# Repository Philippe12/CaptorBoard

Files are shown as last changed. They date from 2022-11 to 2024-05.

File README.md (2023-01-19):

# CaptorBoard
## Decription
Lite automated board with tow relai, one one wire for DHT11, one i2c busse, gpio and UART.
This board is build around a esp32 and designed for Esphome OS.

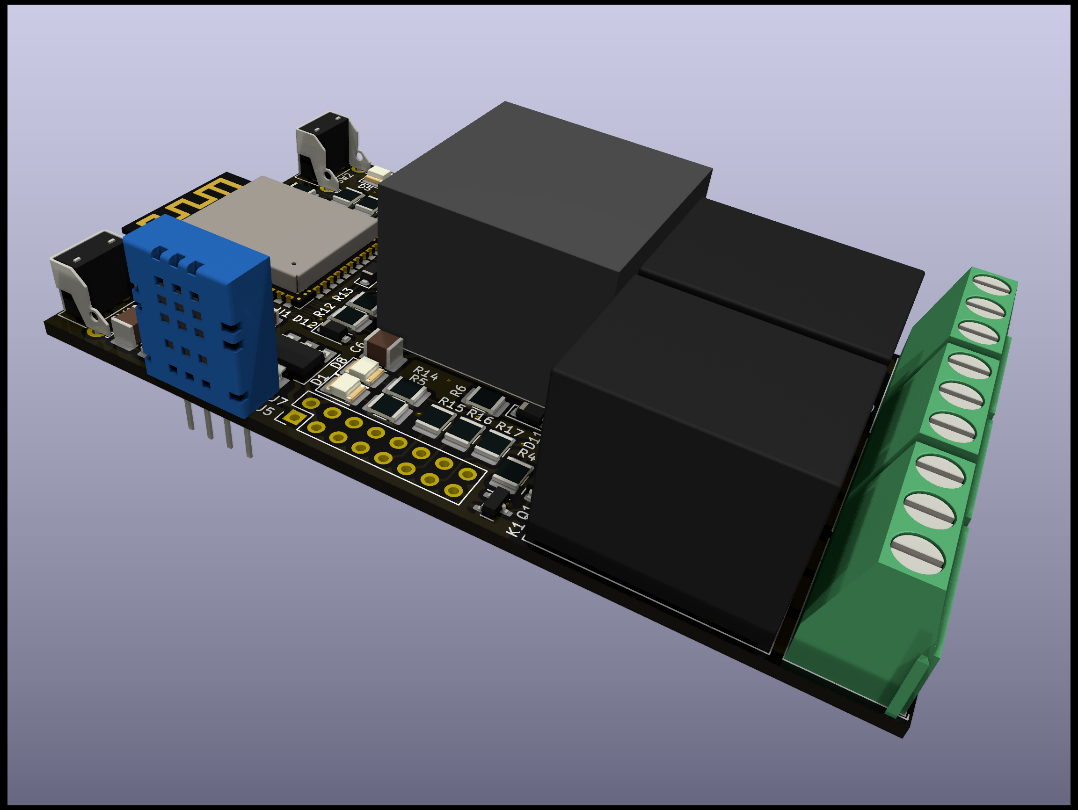
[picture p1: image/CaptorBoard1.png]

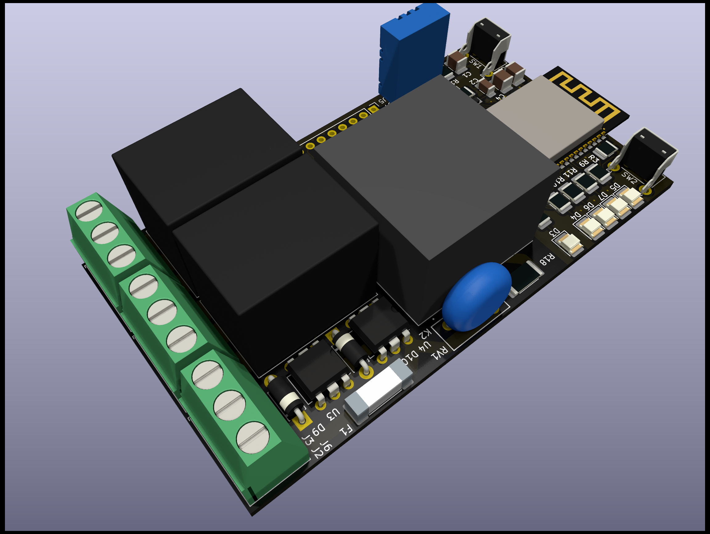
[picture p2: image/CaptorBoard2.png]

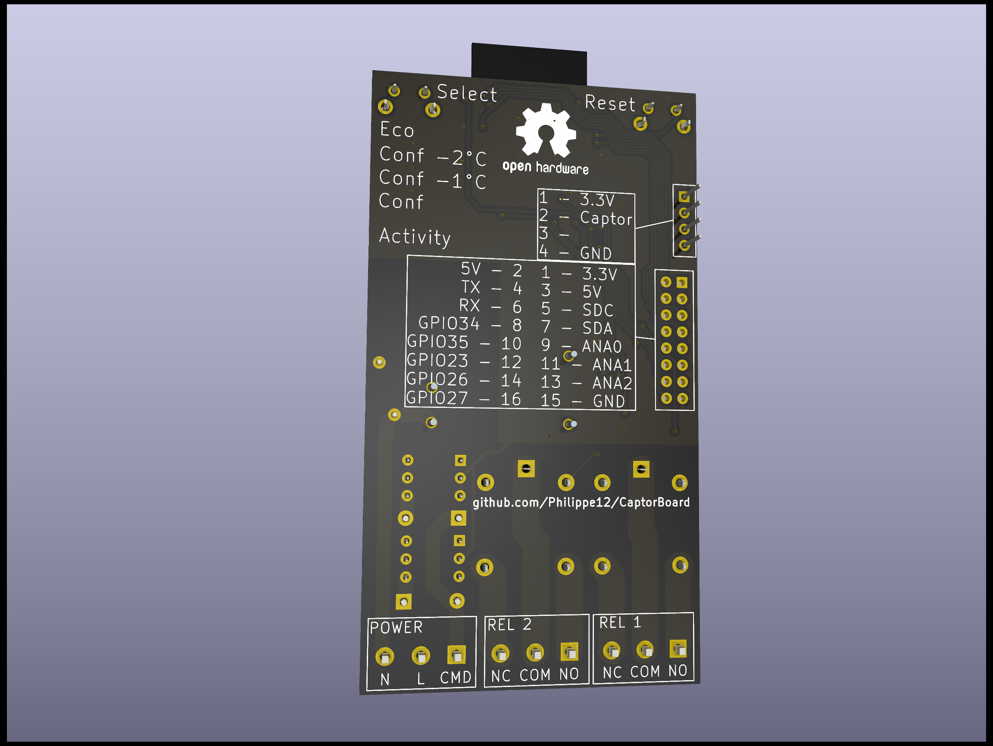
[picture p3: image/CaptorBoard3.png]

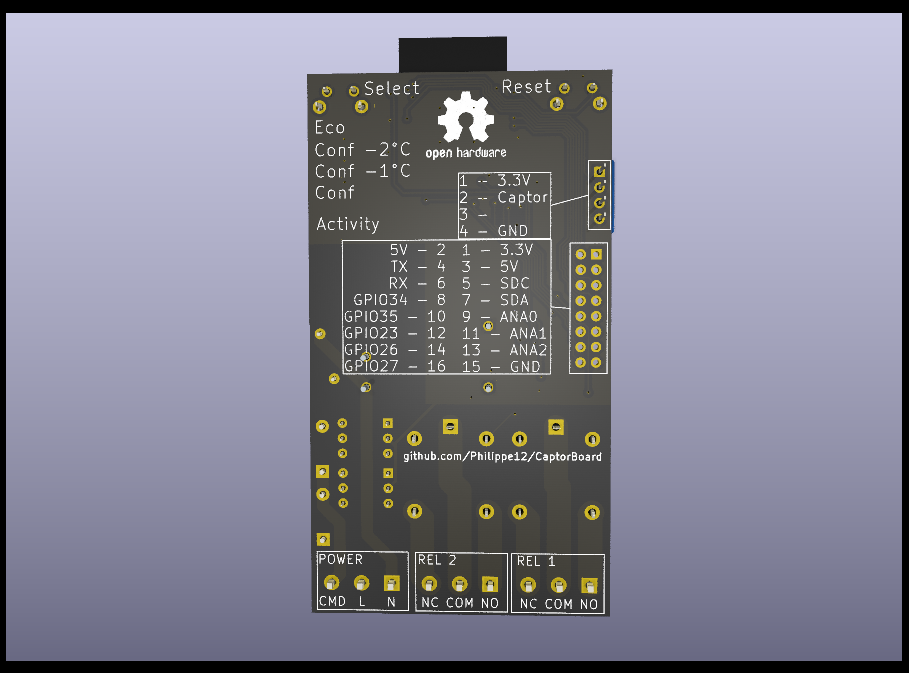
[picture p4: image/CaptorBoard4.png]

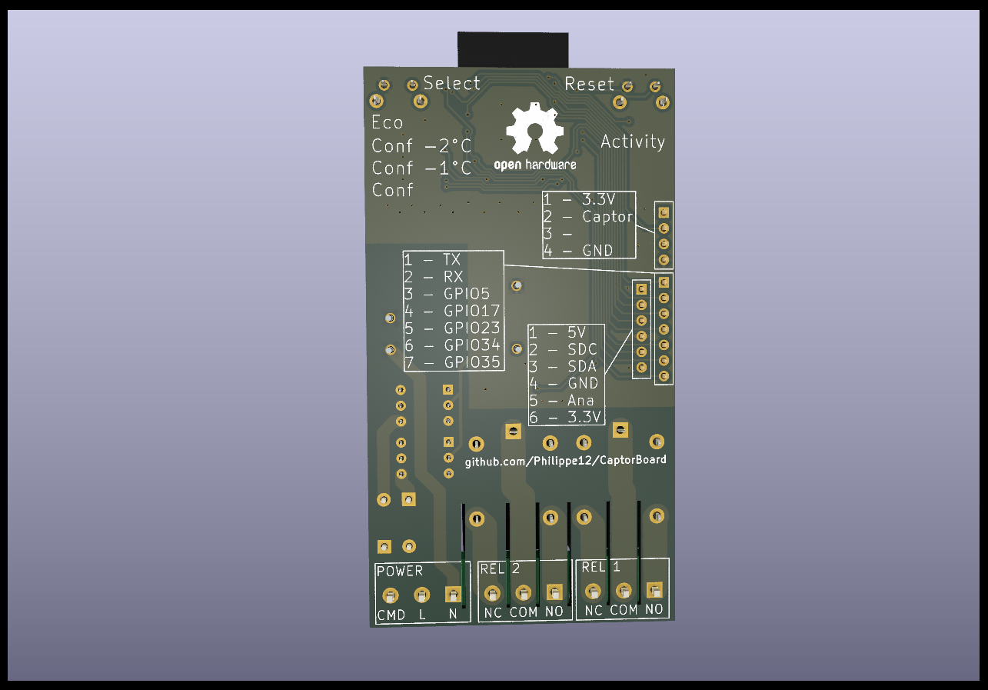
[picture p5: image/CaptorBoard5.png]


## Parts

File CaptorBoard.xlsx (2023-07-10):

Prj: | CaptorBoart |  |  |  | Board Qty: | 1
Co.: |  |  |  |  | Unit Cost: | €26.97
Prj date: | 28/06/2023 17:16:08 |  |  |  | Total Cost: | €26.97 |  |  |  |  | €26.97 | 24 of 24 parts found
$ date: | 2023-06-28 17:16:14
Global Part Info |  |  |  |  |  |  | Digi-Key
Refs | Value | Footprint | Manf# | Qty | Unit$ | Ext$ | Avail | Purch | Unit$ | MOQ | Ext$ | Cat#
C1,C6 | 1µ | C_1210_3225Metric_Pad1.33x2.70mm_HandSolder | CL32B105KBHNNNE (https://www.mouser.fr/datasheet/2/585/MLCC-1837944.pdf) | 2 | €0.210 | €0.42 | 404544 |  | €0.210 | 1 | €0.42 | 1276-1811-1-ND (https://www.digikey.com/en/products/detail/samsung-electro-mechanics/CL32B105KBHNNNE/3887469)
C2,C3 | 12p | C_1206_3216Metric_Pad1.33x1.80mm_HandSolder | C1206C120J5GAC7800 (https://www.mouser.fr/datasheet/2/212/KEM_C1007_X8R_ULTRA_150C_SMD-1102703.pdf) | 2 | €0.201 | €0.40 | 17043 |  | €0.201 | 1 | €0.40 | 399-C1206C120J5GAC7800CT-ND (https://www.digikey.com/en/products/detail/kemet/C1206C120J5GAC7800/411192)
C4 | 22µ | C_1210_3225Metric_Pad1.33x2.70mm_HandSolder | CL32A226MOJNNNE (https://www.mouser.fr/datasheet/2/585/MLCC-1837944.pdf) | 1 | €0.320 | €0.32 | 384377 |  | €0.320 | 1 | €0.32 | 1276-1851-1-ND (https://www.digikey.com/en/products/detail/samsung-electro-mechanics/CL32A226MOJNNNE/3887509)
C5 | 0.1µ | C_1210_3225Metric_Pad1.33x2.70mm_HandSolder | 12101C104K4T2A (https://www.mouser.fr/datasheet/2/40/AutoMLCC-777028.pdf) | 1 | €0.238 | €0.24 | 11066 |  | €0.238 | 1 | €0.24 | 478-KAM32QR72A104KTCT-ND (https://www.digikey.com/en/products/detail/kyocera-avx/KAM32QR72A104KT/6149343)
D1,D3-D8 | LTST-C930KGKT | LED_1210_3225Metric_Pad1.42x2.65mm_HandSolder | LTST-C930KGKT (https://www.mouser.fr/datasheet/2/239/LTST-C930KGKT-1144029.pdf) | 7 | €0.329 | €2.30 | 177523 |  | €0.329 | 1 | €2.30 | 160-1462-1-ND (https://www.digikey.com/en/products/detail/liteon/LTST-C930KGKT/386865)
D2,D11 | 1N4148W | D_SOD-123 | 1N4148W-E3-08 (https://www.vishay.com/docs/85748/1n4148w.pdf) | 2 | €0.210 | €0.42 | 52054 |  | €0.210 | 1 | €0.42 | 1N4148W-E3-08CT-ND (https://www.digikey.com/en/products/detail/vishay-general-semiconductor-diodes-division/1N4148W-E3-08/3104162)
D9,D10 | 1N4004 | D_DO-41_SOD81_P7.62mm_Horizontal | 1N4004RLG (http://www.vishay.com/docs/88503/1n4001.pdf) | 2 | €0.247 | €0.49 | 57339 |  | €0.247 | 1 | €0.49 | 1N4004RLGOSCT-ND (https://www.digikey.com/en/products/detail/onsemi/1N4004RLG/822782)
D12-D14 | BZT52-C3V3 | D_SOD-123F | BZT52-C3V3_R1_00001 (https://diotec.com/tl_files/diotec/files/pdf/datasheets/bzt52b2v4.pdf) | 3 | €0.137 | €0.41 | 12932 |  | €0.137 | 1 | €0.41 | 3757-BZT52-C3V3_R1_00001CT-ND (https://www.digikey.com/en/products/detail/panjit-international-inc/BZT52-C3V3-R1-00001/14660565)
F1 | Fuse_Small-device | Fuseholder_Littelfuse_Nano2_157x | 3405.0166.11 (https://www.mouser.fr/datasheet/2/240/Littelfuse_Fuse_443_Datasheet_pdf-1102277.pdf) | 1 | €0.567 | €0.57 | 235 |  | €0.567 | 1 | €0.57 | 486-4956-ND (https://www.digikey.com/en/products/detail/schurter-inc/3405-0166-11/9094749)
J2,J3,J6 | Screw_Terminal_01x03 | TerminalBlock_Phoenix_MKDS-1,5-3-5.08_1x03_P5.08mm_Horizontal | TB007-508-03BE (https://www.mouser.fr/datasheet/2/670/tb007_508-2306759.pdf) | 3 | €0.887 | €2.66 | 3935 |  | €0.887 | 1 | €2.66 | 102-6204-ND (https://www.digikey.com/en/products/detail/cui-devices/TB007-508-03BE/10064128)
K1,K2 | G5LE-1-DC5 | Relay_SPDT_Omron-G5LE-1 | G5LE-1-DC5 (http://www.omron.com/ecb/products/pdf/en-g5le.pdf) | 2 | €1.518 | €3.04 | 6959 |  | €1.518 | 1 | €3.04 | Z1014-ND (https://www.digikey.com/en/products/detail/omron-electronics-inc-emc-div/G5LE-1-DC5/280368)
PS1 | LD03-23B05R2 | PSK5D5 | LD03-23B05R2 (https://www.mouser.fr/datasheet/2/670/psk_5d-2474718.pdf) | 1 | €4.873 | €4.87 | 10414 |  | €4.873 | 1 | €4.87 | 2725-LD03-23B05R2-ND (https://www.digikey.com/en/products/detail/mornsun-america-llc/LD03-23B05R2/13531047)
Q1,Q2 | 2N7002E | SOT-23 | T2N7002BK,LM (http://www.diodes.com/assets/Datasheets/ds30376.pdf) | 2 | €0.155 | €0.31 | 266755 |  | €0.155 | 1 | €0.31 | T2N7002BKLMCT-ND (https://www.digikey.com/en/products/detail/toshiba-semiconductor-and-storage/T2N7002BK-LM/5409245)
R1,R5,R7-R11,R14 | 1k | R_1210_3225Metric_Pad1.30x2.65mm_HandSolder | RMCF1210JT1K00 (https://www.mouser.fr/datasheet/2/210/Kamaya_RMC_series_8_2022-3032447.pdf) | 8 | €0.110 | €0.88 | 207265 |  | €0.110 | 1 | €0.88 | RMCF1210JT1K00CT-ND (https://www.digikey.com/en/products/detail/stackpole-electronics-inc/RMCF1210JT1K00/1757278)
R2 | 5M | R_1210_3225Metric_Pad1.30x2.65mm_HandSolder | CRMA1210AF4M99FKEF (https://www.mouser.fr/datasheet/2/427/crma-1765222.pdf) | 1 | €0.631 | €0.63 | 7720 |  | €0.631 | 1 | €0.63 | 3579-CRMA1210AF4M99FKEFCT-ND (https://www.digikey.com/en/products/detail/vishay-techno/CRMA1210AF4M99FKEF/13998628)
R3,R4,R6,R15-R17 | 10k | R_1210_3225Metric_Pad1.30x2.65mm_HandSolder | RMCF1210FT10K0 (https://www.mouser.fr/datasheet/2/219/RK73B-1825463.pdf) | 6 | €0.128 | €0.77 | 17980 |  | €0.128 | 1 | €0.77 | RMCF1210FT10K0CT-ND (https://www.digikey.com/en/products/detail/stackpole-electronics-inc/RMCF1210FT10K0/1758528)
R12,R13 | 560R | R_1210_3225Metric_Pad1.30x2.65mm_HandSolder | RK73B2ETTD561J (https://www.mouser.fr/datasheet/2/219/RK73B-1825463.pdf) | 2 | €0.128 | €0.26 | 15215 |  | €0.128 | 1 | €0.26 | 2019-RK73B2ETTD561JCT-ND (https://www.digikey.com/en/products/detail/koa-speer-electronics-inc/RK73B2ETTD561J/10314965)
R18 | 12 | R_2512_6332Metric_Pad1.40x3.35mm_HandSolder | 352212RJT | 1 | €0.622 | €0.62 | 113856 |  | €0.622 | 1 | €0.62 | A121136CT-ND (https://www.digikey.com/en/products/detail/te-connectivity-passive-product/352212RJT/5244987)
RV1 | B72210S0351K101 | RV_Disc_D12mm_W5.1mm_P7.5mm | B72210S0351K101 | 1 | €0.466 | €0.47 | 6900 |  | €0.466 | 1 | €0.47 | 495-6461-ND (https://www.digikey.com/en/products/detail/epcos-tdk-electronics/B72210S0351K101/3500863)
SW1,SW2 | SW_PUSH | SW_Tactile_SKHH_Angled | TL1105VF100Q (https://www.mouser.fr/datasheet/2/15/SKHH-1370651.pdf) | 2 | €0.338 | €0.68 | 66274 |  | €0.338 | 1 | €0.68 | EG2507-ND (https://www.digikey.com/en/products/detail/e-switch/TL1105VF100Q/378973)
U1 | ESP32-WROOM-32E-H4 | ESP32-WROOM-32E | ESP32-WROOM-32E-H4 (https://www.espressif.com/sites/default/files/documentation/esp32-wroom-32e_esp32-wroom-32ue_datasheet_en.pdf) | 1 | €2.880 | €2.88 | 9799 |  | €2.880 | 1 | €2.88 | 1965-ESP32-WROOM-32E-H4CT-ND (https://www.digikey.com/en/products/detail/espressif-systems/ESP32-WROOM-32E-H4/12696413)
U2 | TC1264-3.3VDBTR | SOT-223-3_TabPin2 | TC1264-3.3VDBTR (http://ww1.microchip.com/downloads/en/DeviceDoc/21373C.pdf) | 1 | €0.832 | €0.83 | 545 |  | €0.832 | 1 | €0.83 | TC1264-3.3VDBCT-ND (https://www.digikey.com/en/products/detail/microchip-technology/TC1264-3-3VDBTR/443075)
U3,U4 | MOC3041M-opto | DIP-6_W7.62mm | MOC3041M (https://www.mouser.fr/datasheet/2/308/1/MOC3043M_D-1811826.pdf) | 2 | €0.978 | €1.96 | 4749 |  | €0.978 | 1 | €1.96 | MOC3041M-ND (https://www.digikey.com/en/products/detail/onsemi/MOC3041M/281230)
Y1 | CM8V-T1A-32.768kHz-12.5pF-20PPM-TA-QC | Crystal_SMD_MicroCrystal_CC8V-T1A-2Pin_2.0x1.2mm_HandSoldering | CM8V-T1A-32.768kHz-12.5pF-20PPM-TA-QC (https://www.mouser.fr/datasheet/2/530/CM8V_T1A-1510858.pdf) | 1 | €0.549 | €0.55 | 93569 |  | €0.549 | 1 | €0.55 | 2195-CM8V-T1A-32.768KHZ-12.5PF-20PPM-TA-QCCT-ND (https://www.digikey.com/en/products/detail/micro-crystal-ag/CM8V-T1A-32-768KHZ-12-5PF-20PPM-TA-QC/10431068)
 | EUR(€)/USD($): | 0.9142439203 |  |  | Total Purchase: | €0.00 | Buy here (https://www.digikey.com/ordering/shoppingcart) |  |  |  | €0.00
 |  |  |  |  | Purchase description:
KiCost® v1.1.18

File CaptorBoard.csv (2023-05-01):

Source: | /Users/philippefouquet/Documents/Developpement/Electronique/CaptorBoard/CaptorBoard.kicad_sch
Date: | 2023 May 01, Monday 16:40:26
Tool: | Eeschema 7.0.2-0
Generator: | /Applications/KiCad/KiCad.app/Contents/SharedSupport/plugins/bom_csv_grouped_by_value.py
Component Count: | 47
Collated Components:
Item | Qty | Reference(s) | Value | LibPart | Footprint | Datasheet | DNP | Sim.Device | Sim.Enable | Sim.Pins | manf#
1 | 2 | C1, C5 | 0.1µ | Device:C | Capacitor_SMD:C_1210_3225Metric_Pad1.33x2.70mm_HandSolder | https://www.mouser.fr/datasheet/2/40/AutoMLCC-777028.pdf |  |  |  |  | 12101C104K4T2A
2 | 2 | C2, C3 | 12p | Device:C | Capacitor_SMD:C_1210_3225Metric_Pad1.33x2.70mm_HandSolder | https://www.mouser.fr/datasheet/2/212/KEM_C1007_X8R_ULTRA_150C_SMD-1102703.pdf |  |  |  |  | C1210C120J1HACTU
3 | 1 | C4 | 22µ | Device:C | Capacitor_SMD:C_1210_3225Metric_Pad1.33x2.70mm_HandSolder | https://www.mouser.fr/datasheet/2/585/MLCC-1837944.pdf |  |  |  |  | CL32A226MOJNNNE
4 | 1 | C6 | 1µ | Device:C | Capacitor_SMD:C_1210_3225Metric_Pad1.33x2.70mm_HandSolder | https://www.mouser.fr/datasheet/2/585/MLCC-1837944.pdf |  |  |  |  | CL32B105KBHNNNE
5 | 7 | D1, D3, D4, D5, D6, D7, D8 | LTST-C930KGKT | Device:LED | LED_SMD:LED_1210_3225Metric_Pad1.42x2.65mm_HandSolder | https://www.mouser.fr/datasheet/2/239/LTST-C930KGKT-1144029.pdf |  |  |  |  | LTST-C930KGKT
6 | 2 | D2, D11 | 1N4148W | Diode:1N4148W | Diode_SMD:D_SOD-123 | https://www.vishay.com/docs/85748/1n4148w.pdf |  | D |  | 1=K 2=A | 1N4148W-E3-08
7 | 2 | D9, D10 | 1N4004 | Diode:1N4004 | Diode_THT:D_DO-41_SOD81_P7.62mm_Horizontal | http://www.vishay.com/docs/88503/1n4001.pdf |  | D |  | 1=K 2=A | 1N4004T-G
8 | 1 | F1 | Fuse_Small-device | CaptorBoard-rescue:Fuse_Small-device | Fuse:Fuseholder_Littelfuse_Nano2_157x | https://www.mouser.fr/datasheet/2/240/Littelfuse_Fuse_443_Datasheet_pdf-1102277.pdf |  |  |  |  | 0443001.DR
9 | 3 | J2, J3, J6 | Screw_Terminal_01x03 | Connector:Screw_Terminal_01x03 | TerminalBlock_Phoenix:TerminalBlock_Phoenix_MKDS-1,5-3-5.08_1x03_P5.08mm_Horizontal | https://www.mouser.fr/datasheet/2/670/tb007_508-2306759.pdf |  |  |  |  | TB007-508-03BE
10 | 2 | K1, K2 | G5LE-1-DC5 | Relay:G5LE-1 | Relay_THT:Relay_SPDT_Omron-G5LE-1 | http://www.omron.com/ecb/products/pdf/en-g5le.pdf |  |  |  |  | G5LE-1-DC5
11 | 1 | PS1 | PSK-5D-5 | pfo:PSK-5D-5 | pfo:PSK5D5 | https://www.mouser.fr/datasheet/2/670/psk_5d-2474718.pdf |  |  |  |  | PSK-5D-5
12 | 2 | Q1, Q2 | 2N7002E | Transistor_FET:2N7002E | Package_TO_SOT_SMD:SOT-23 | http://www.diodes.com/assets/Datasheets/ds30376.pdf |  |  |  |  | 2N7002E-7-F
13 | 8 | R1, R5, R7, R8, R9, R10, R11, R14 | 1k | Device:R | Resistor_SMD:R_1210_3225Metric_Pad1.30x2.65mm_HandSolder | https://www.mouser.fr/datasheet/2/210/Kamaya_RMC_series_8_2022-3032447.pdf |  |  |  |  | RMC1/4-102JTE
14 | 1 | R2 | 5M | Device:R | Resistor_SMD:R_1210_3225Metric_Pad1.30x2.65mm_HandSolder | https://www.mouser.fr/datasheet/2/427/crma-1765222.pdf |  |  |  |  | CRMA1210AF4M99FKEF
15 | 3 | R3, R4, R6 | 10k | Device:R | Resistor_SMD:R_1210_3225Metric_Pad1.30x2.65mm_HandSolder | https://www.mouser.fr/datasheet/2/219/RK73B-1825463.pdf |  |  |  |  | RMCF1210FT10K0
16 | 2 | R12, R13 | 560R | Device:R | Resistor_SMD:R_1210_3225Metric_Pad1.30x2.65mm_HandSolder | https://www.mouser.fr/datasheet/2/219/RK73B-1825463.pdf |  |  |  |  | RK73B2ETTD561J
17 | 2 | SW1, SW2 | SW_PUSH | CaptorBoard-rescue:SW_PUSH | Button_Switch_THT:SW_Tactile_SKHH_Angled | https://www.mouser.fr/datasheet/2/15/SKHH-1370651.pdf |  |  |  |  | SKHHLPA010
18 | 1 | U1 | ESP32-WROOM-32E-N4 | Espressif:ESP32-WROOM-E | Espressif:ESP32-WROOM-32E | https://www.espressif.com/sites/default/files/documentation/esp32-wroom-32e_esp32-wroom-32ue_datasheet_en.pdf |  |  |  |  | ESP32-WROOM-32E-N4
19 | 1 | U2 | TC1264-3.3VDBTR | Regulator_Linear:TC1262-33 | Package_TO_SOT_SMD:SOT-223-3_TabPin2 | http://ww1.microchip.com/downloads/en/DeviceDoc/21373C.pdf |  |  |  |  | TC1264-3.3VDBTR
20 | 1 | U3 | MOC3041M-opto | :MOC3041M-opto_1 | Package_DIP:DIP-6_W7.62mm | https://www.mouser.fr/datasheet/2/308/1/MOC3043M_D-1811826.pdf |  |  |  |  | MOC3041M
21 | 1 | U4 | MOC3041M-opto | CaptorBoard-rescue:MOC3041M-opto | Package_DIP:DIP-6_W7.62mm | https://www.mouser.fr/datasheet/2/308/1/MOC3043M_D-1811826.pdf |  |  |  |  | MOC3041M
22 | 1 | Y1 | CM8V-T1A-32.768kHz-12.5pF-20PPM-TA-QC | Device:Crystal | Crystal:Crystal_SMD_MicroCrystal_CC8V-T1A-2Pin_2.0x1.2mm_HandSoldering | https://www.mouser.fr/datasheet/2/530/CM8V_T1A-1510858.pdf |  |  |  |  | CM8V-T1A-32.768kHz-12.5pF-20PPM-TA-QC

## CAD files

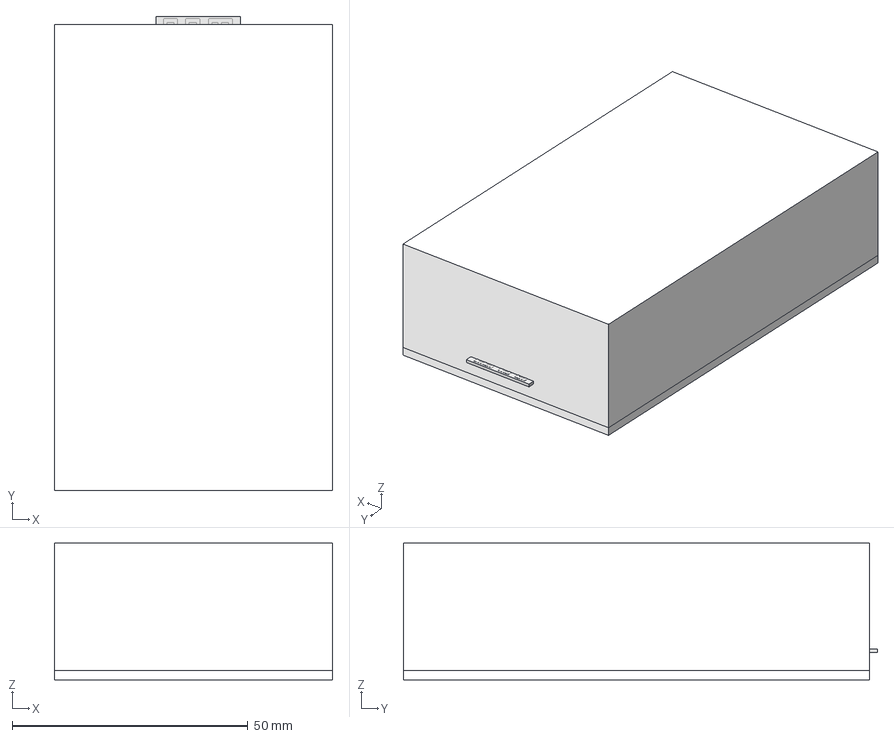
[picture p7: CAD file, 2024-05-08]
Box/Back.FCStd
59.0 x 100.7 x 29.0 mm
ESP32-WROOM-32E
D_DO-41_SOD81_P7.62mm_Horizontal
D_DO-41_SOD81_P7.62mm_Horizontal002
R_1210_3225Metric
R_1210_3225Metric002
R_1210_3225Metric004
R_1210_3225Metric006
R_1210_3225Metric008
LED_1210_3225Metric
LED_1210_3225Metric002
LED_1210_3225Metric004
LED_1210_3225Metric006
LED_1210_3225Metric008
TerminalBlock_Phoenix_MKDS_15_3_508_1x03_P508mm_Horizontal
SW_Tactile_SPST_Angled_PTS645Vx31-2LFS
SW_Tactile_SPST_Angled_PTS645Vx31-2LFS002
DIP-6_W7.62mm
DIP-6_W7.62mm002
R_1210_3225Metric010
R_1210_3225Metric012
ASSEMBLY
C_1210_3225Metric
R_1210_3225Metric014
RV_Disc_D12mm_W51mm_P75mm
MicroCrystal_CC8V_T1A
R_1210_3225Metric016
C_1210_3225Metric002
R_1210_3225Metric018
SOT_23
C_1206_3216Metric
SOT_024
Relay_SPDT_Omron-G5LE-1
R_2512_6332Metric
D_SOD_123
TerminalBlock_Phoenix_MKDS_15_3_508_1x03_P508mm_Horizontal001
LED_1210_3225Metric010
R_1210_3225Metric020
R_1210_3225Metric022
C_1210_3225Metric004
D_SOD_123F
D_SOD_123F001
R_1210_3225Metric024
R_1210_3225Metric026
R_1210_3225Metric028
C_1206_3216Metric002
R_1210_3225Metric030
SOT_223
ASSEMBLY001
D_SOD_124
C_1210_3225Metric006
TerminalBlock_Phoenix_MKDS_15_3_508_1x03_P508mm_Horizontal002
R_1210_3225Metric032
Relay_SPDT_Omron-G5LE-003
D_SOD_123F002
LED_1210_3225Metric012
CaptorBoard_track_1
CaptorBoard_track_2
CaptorBoard_track_3
CaptorBoard_track_4
CaptorBoard_track_5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

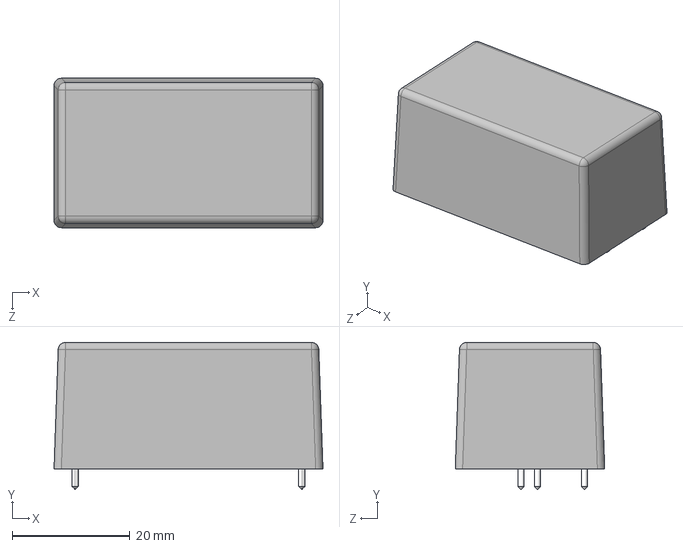
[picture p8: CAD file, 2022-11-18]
3D/IRM-05-5.stp
45.7 x 25.0 x 25.4 mm

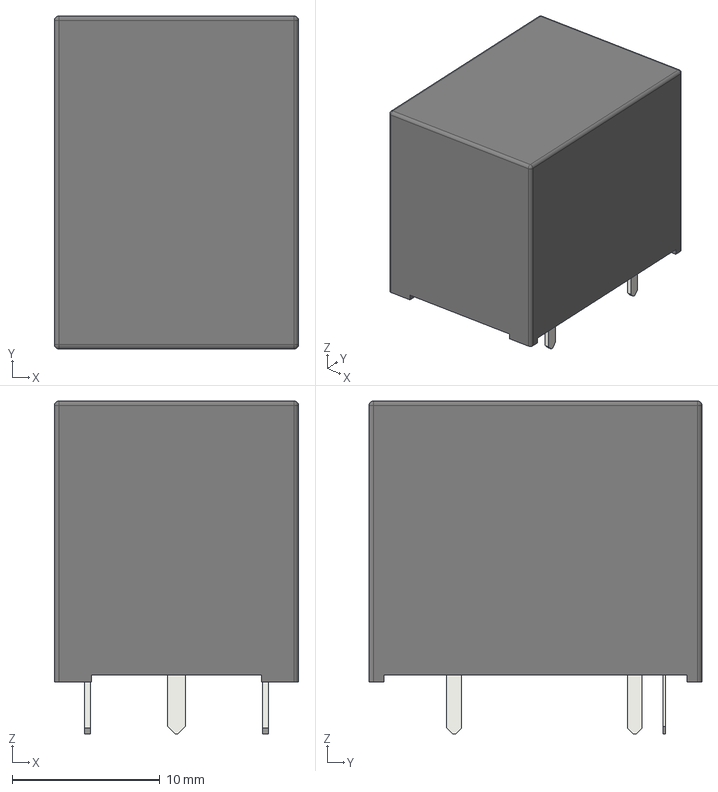
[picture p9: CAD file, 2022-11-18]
3D/Relay_SPDT_Omron-G5LE-1.step
16.5 x 22.5 x 22.5 mm

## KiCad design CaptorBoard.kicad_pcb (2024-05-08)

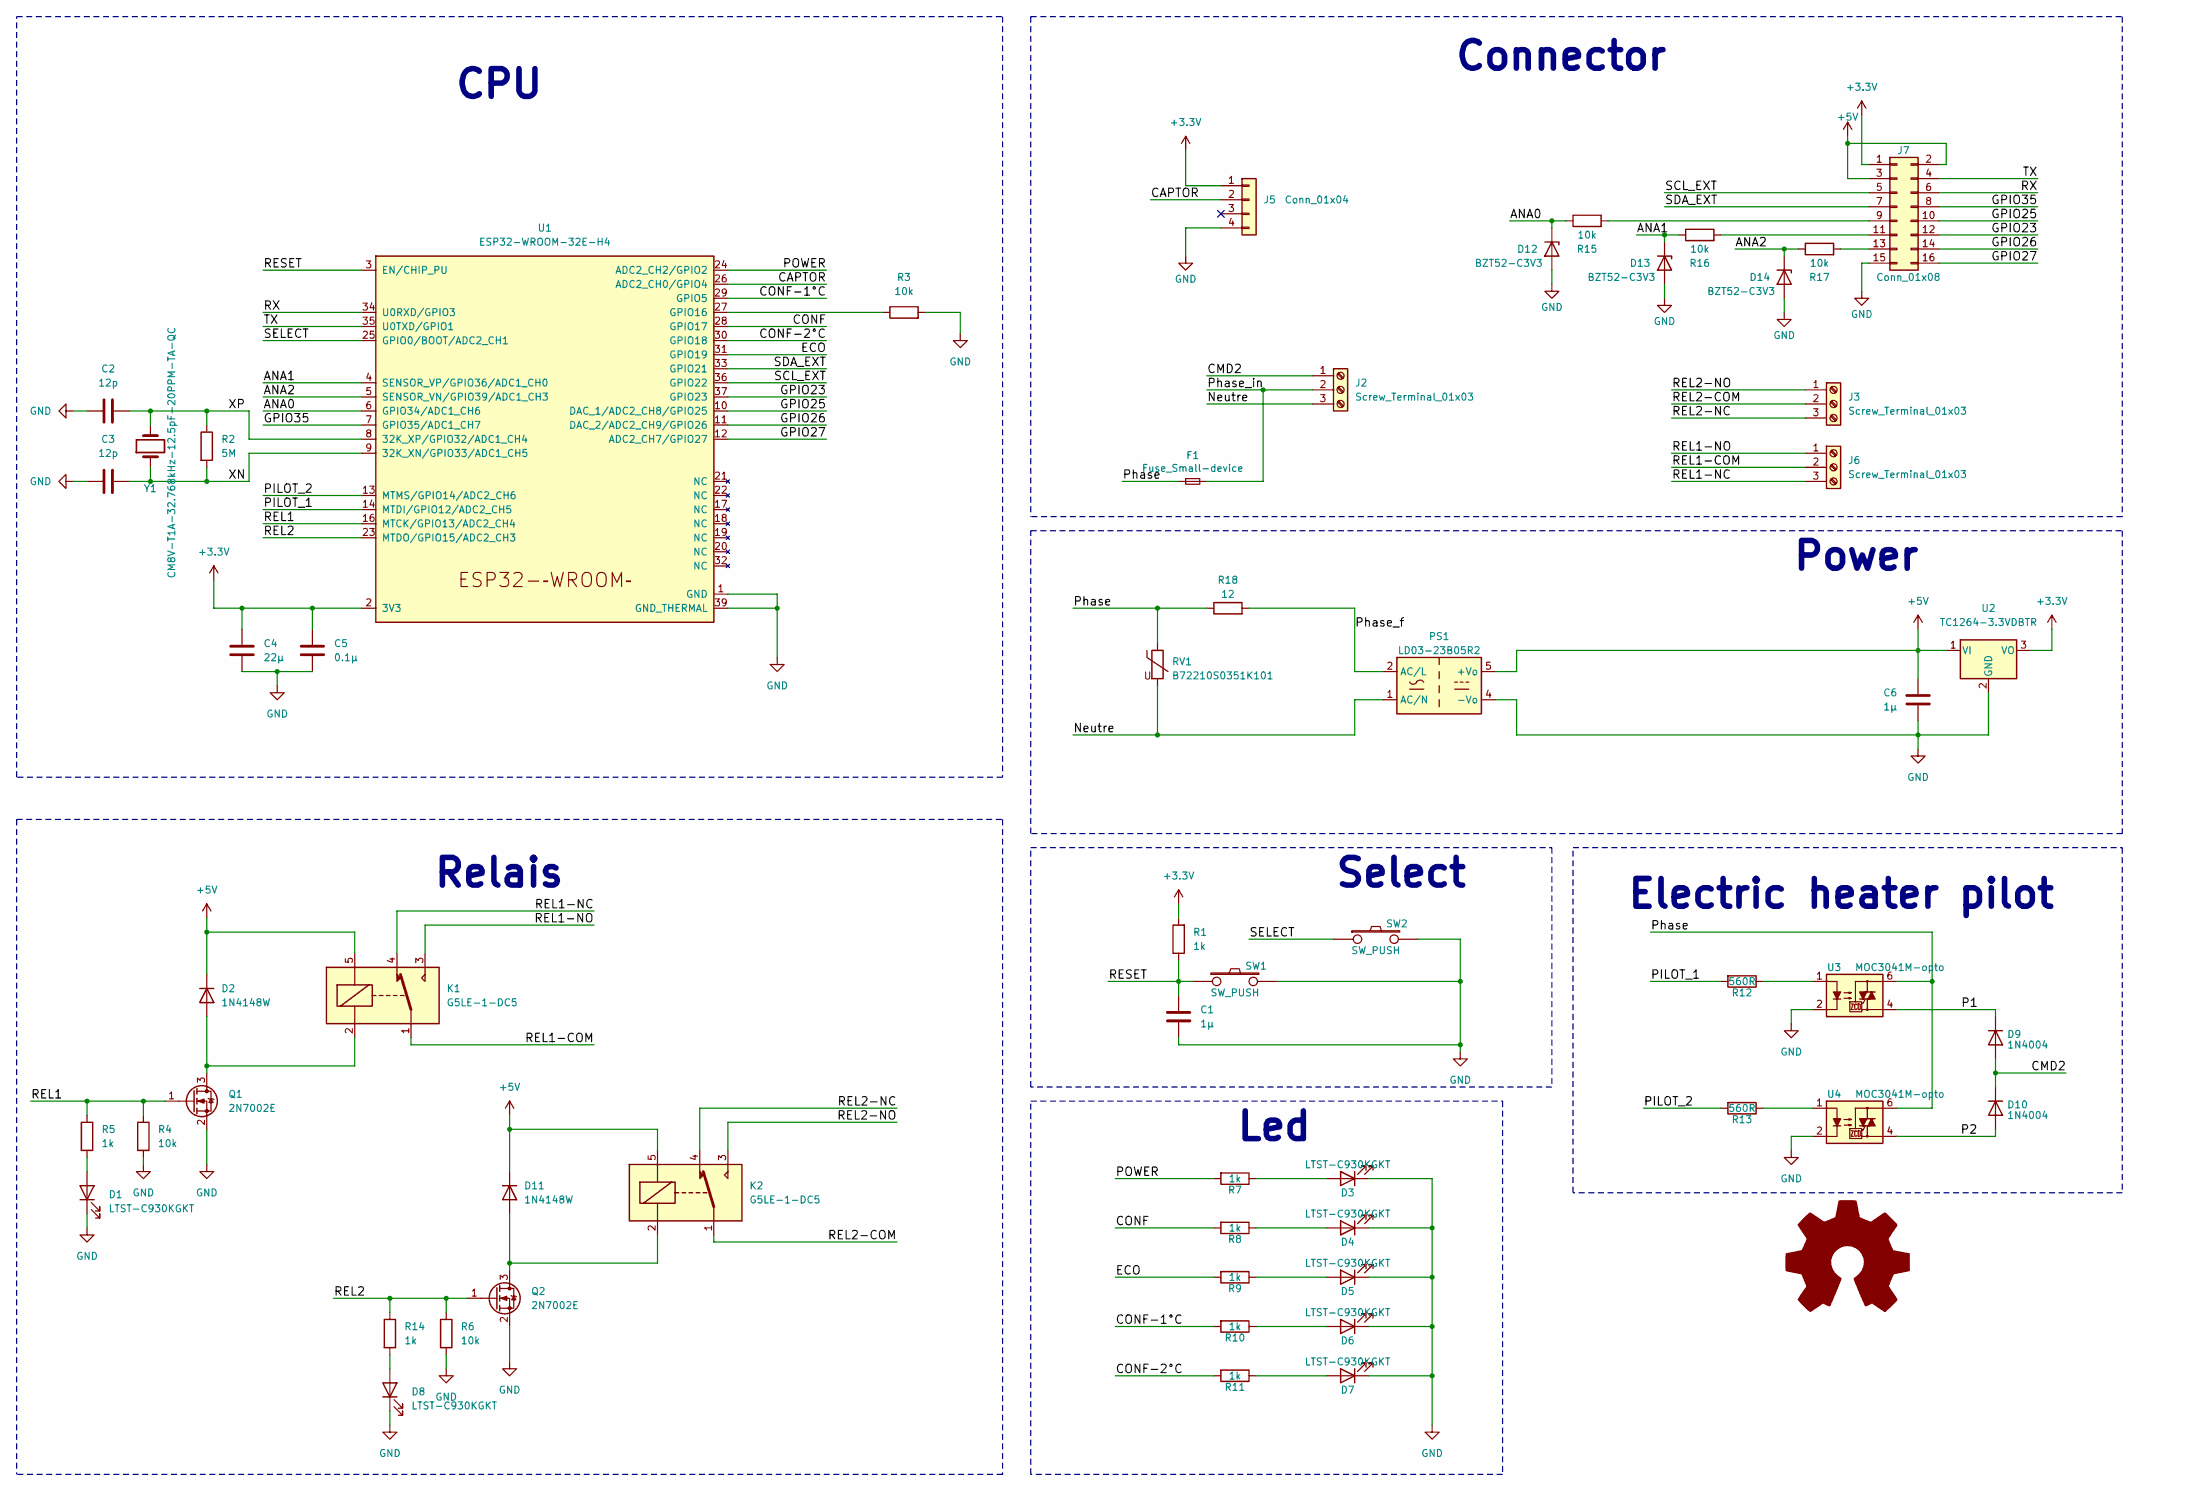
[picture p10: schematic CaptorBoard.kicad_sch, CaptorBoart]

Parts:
C1, C6: 1µ; C_1210_3225Metric_Pad1.33x2.70mm_HandSolder
C2, C3: 12p; C_1206_3216Metric_Pad1.33x1.80mm_HandSolder
C4: 22µ; C_1210_3225Metric_Pad1.33x2.70mm_HandSolder
C5: 0.1µ; C_1210_3225Metric_Pad1.33x2.70mm_HandSolder
D1, D3, D4, D5, D6, D7, D8: LTST-C930KGKT; LED_1210_3225Metric_Pad1.42x2.65mm_HandSolder
D2, D11: 1N4148W; D_SOD-123
D9, D10: 1N4004; D_DO-41_SOD81_P7.62mm_Horizontal
D12, D13, D14: BZT52-C3V3; D_SOD-123F
F1: Fuse_Small-device; Fuse_Schurter_UMT250
J2, J3, J6: Screw_Terminal_01x03; TerminalBlock_Phoenix_MKDS-1,5-3-5.08_1x03_P5.08mm_Horizont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
J5: Conn_01x04; PinHeader_1x04_P2.54mm_Vertical
J7: Conn_01x08; PinHeader_2x08_P2.54mm_Vertical
K1, K2: G5LE-1-DC5; Relay_SPDT_Omron-G5LE-1
PS1: LD03-23B05R2; PSK5D5
Q1, Q2: 2N7002E; SOT-23
R1, R5, R7, R8, R9, R10, R11, R14: 1k; R_1210_3225Metric_Pad1.30x2.65mm_HandSolder
R2: 5M; R_1210_3225Metric_Pad1.30x2.65mm_HandSolder
R3, R4, R6, R15, R16, R17: 10k; R_1210_3225Metric_Pad1.30x2.65mm_HandSolder
R12, R13: 560R; R_1210_3225Metric_Pad1.30x2.65mm_HandSolder
R18: 12; R_2512_6332Metric_Pad1.40x3.35mm_HandSolder
RV1: B72210S0351K101; RV_Disc_D12mm_W5.1mm_P7.5mm
SW1, SW2: SW_PUSH; SW_Tactile_SKHH_Angled
SYM1: Logo_Open_Hardware_Large; OSHW-Logo2_14.6x12mm_SilkScreen
U1: ESP32-WROOM-32E-H4; ESP32-WROOM-32E
U2: TC1264-3.3VDBTR; SOT-223-3_TabPin2
U3, U4: MOC3041M-opto; DIP-6_W7.62mm
Y1: CM8V-T1A-32.768kHz-12.5pF-20PPM-TA-QC; Crystal_SMD_MicroCrystal_CC8V-T1A-2Pin_2.0x1.2mm_HandSolder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

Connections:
+3.3V: C4.1, C5.1, J5.1, J7.1, R1.2, U1.2 (3V3), U2.3 (VO)
+5V: C6.1, D2.1 (K), D11.1 (K), J7.2, J7.3, K1.5, K2.5, PS1.5 (+Vo), U2.1 (VI)
/ANA0: D12.1 (K), R15.1, U1.6 (GPIO34/ADC1_CH6)
/ANA1: D13.1 (K), R16.1, U1.4 (SENSOR_VP/GPIO36/ADC1_CH0)
/ANA2: D14.1 (K), R17.1, U1.5 (SENSOR_VN/GPIO39/ADC1_CH3)
/CAPTOR: J5.2, U1.26 (ADC2_CH0/GPIO4)
/CMD2: D9.2 (A), D10.1 (K), J2.1
/CONF: R8.2, U1.28 (GPIO17)
/CONF-1°C: R10.2, U1.29 (GPIO5)
/CONF-2°C: R11.2, U1.30 (GPIO18)
/ECO: R9.2, U1.31 (GPIO19)
/GPIO23: J7.12, U1.37 (GPIO23)
/GPIO25: J7.10, U1.10 (DAC_1/ADC2_CH8/GPIO25)
/GPIO26: J7.14, U1.11 (DAC_2/ADC2_CH9/GPIO26)
/GPIO27: J7.16, U1.12 (ADC2_CH7/GPIO27)
/GPIO35: J7.8, U1.7 (GPIO35/ADC1_CH7)
/Neutre: J2.3, PS1.1 (AC/N), RV1.2
/P1: D9.1 (K), U3.4
/P2: D10.2 (A), U4.4
/PILOT_1: R12.2, U1.14 (MTDI/GPIO12/ADC2_CH5)
/PILOT_2: R13.2, U1.13 (MTMS/GPIO14/ADC2_CH6)
/POWER: R7.2, U1.24 (ADC2_CH2/GPIO2)
/Phase: F1.1, R18.1, RV1.1, U3.6, U4.6
/Phase_f: PS1.2 (AC/L), R18.2
/Phase_in: F1.2, J2.2
/REL1: Q1.1 (G), R4.1, R5.1, U1.16 (MTCK/GPIO13/ADC2_CH4)
/REL1-COM: J6.2, K1.1
/REL1-NC: J6.3, K1.4
/REL1-NO: J6.1, K1.3
/REL2: Q2.1 (G), R6.1, R14.1, U1.23 (MTDO/GPIO15/ADC2_CH3)
/REL2-COM: J3.2, K2.1
/REL2-NC: J3.3, K2.4
/REL2-NO: J3.1, K2.3
/RESET: C1.1, R1.1, SW1.1, U1.3 (EN/CHIP_PU)
/RX: J7.6, U1.34 (U0RXD/GPIO3)
/SCL_EXT: J7.5, U1.36 (GPIO22)
/SDA_EXT: J7.7, U1.33 (GPIO21)
/SELECT: SW2.1, U1.25 (GPIO0/BOOT/ADC2_CH1)
/TX: J7.4, U1.35 (U0TXD/GPIO1)
/XN: C3.2, R2.2, U1.9 (32K_XN/GPIO33/ADC1_CH5), Y1.1
/XP: C2.2, R2.1, U1.8 (32K_XP/GPIO32/ADC1_CH4), Y1.2
GND: C1.2, C2.1, C3.1, C4.2, C5.2, C6.2, D1.1 (K), D3.1 (K), D4.1 (K), D5.1 (K), D6.1 (K), D7.1 (K), D8.1 (K), D12.2 (A), D13.2 (A), D14.2 (A), J5.4, J7.15, PS1.4 (-Vo), Q1.2 (S), Q2.2 (S), R3.2, R4.2, R6.2, SW1.2, SW2.2, U1.1 (GND), U1.15 (GND), U1.38 (GND), U1.39 (GND_THERMAL), U2.2 (GND), U3.2, U4.2
unnamed: D1.2 (A), R5.2
unnamed: D2.2 (A), K1.2, Q1.3 (D)
unnamed: D3.2 (A), R7.1
unnamed: D4.2 (A), R8.1
unnamed: D5.2 (A), R9.1
unnamed: D6.2 (A), R10.1
unnamed: D7.2 (A), R11.1
unnamed: D8.2 (A), R14.2
unnamed: D11.2 (A), K2.2, Q2.3 (D)
unnamed: J7.9, R15.2
unnamed: J7.11, R16.2
unnamed: J7.13, R17.2
unnamed: R12.1, U3.1
unnamed: R13.1, U4.1
unnamed: R3.1, U1.27 (GPIO16)

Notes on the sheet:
Power
Led
CPU
Select
Electric heater pilot
Connector
Relais

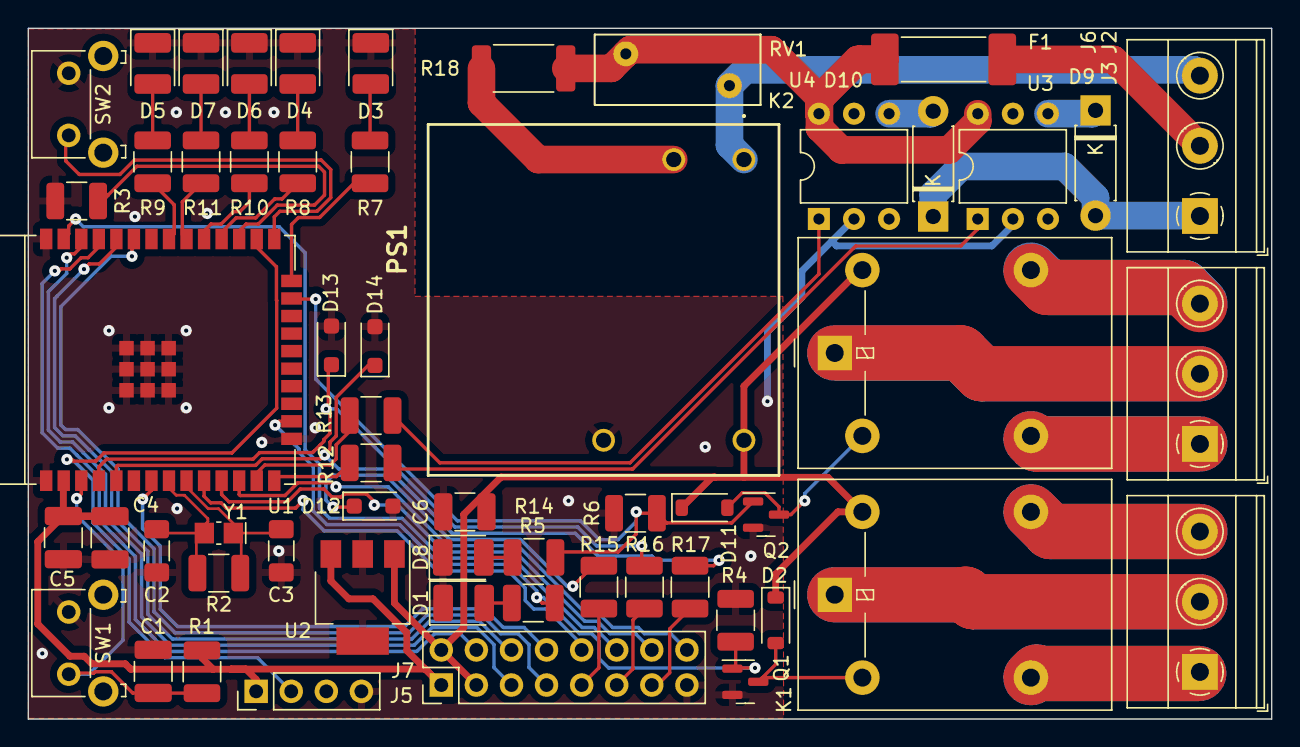
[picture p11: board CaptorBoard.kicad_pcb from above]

Board: 2 copper layers, 90.0 x 50.0 mm, 58 parts (1 on the bottom side), 57 nets.

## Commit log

2015-02-15 Add SHT25 to shema
    [Sendor_Board.sch]
2015-02-18 Add net USBID
    [Sendor_Board.sch]
2015-02-19 Add I2C bus for SHT25
    [Sendor_Board.sch]
2015-02-21 Add MPL115A2 to schematic
    [Sendor_Board.sch]
2015-02-21 Change placement
    [Sendor_Board.sch]
2015-02-21 Add MRF24J40MA to schematic
    [Sendor_Board.sch]
2015-03-21 Add electric radiator pilot function
    [Sendor_Board.sch]
2015-03-22 Change all presentation an add a frame
    [Sendor_Board.sch]
2015-03-22 Add 3,3V decoupling capacitor
    [Sendor_Board.sch]
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2015-03-29 Insert Power convertor
    [Sendor_Board.sch]
2015-03-30 insert led
    [Sendor_Board.sch]
2015-03-30 Change command PILOT_x from std output to PWM output
    [Sendor_Board.sch]
2015-03-30 Move button to int input
    [Sendor_Board.sch]
2015-03-30 Change PHOENIX connector type
    [Sendor_Board.sch]
2015-03-31 Small change for better display
    [Sendor_Board.sch]
2015-04-04 Some correction
    [Sendor_Board.sch]
2015-04-06 Correct the PIC32MX bin asignement
    [Sendor_Board.sch]
2015-04-09 Large change convert project to Kickad It is better to use a open sources project
    [CaptorBoard.sch, Sendor_Board.sch]
2015-04-09 Set all foot print
    [CaptorBoard.sch]
2015-04-19 Change LED foot print Add extension conector
    [CaptorBoard.sch]
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2015-04-19 Some ERC correction
    [CaptorBoard.sch]
2015-04-19 Change led pin order for routing facility
    [CaptorBoard.sch]
2015-04-21 Place Fuse before all
    [CaptorBoard.sch]
2015-04-21 Change converter AC/DC The old one to height for the case
    [CaptorBoard.sch]
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2015-04-21 Forgot foot print
    [CaptorBoard.sch]
2015-04-21 Add marker for 5V
    [CaptorBoard.sch]
2015-04-23 Change HST21
    [CaptorBoard.sch]
2015-04-23 First PCB
    [CaptorBoard.kicad_pcb]
2015-04-25 3D form
    [CaptorBoard.kicad_pcb]
2015-04-25 Change mark position
    [CaptorBoard.kicad_pcb]
2015-04-26 Replace Value 550 ohm to 560ohm (mormailsition)
    [CaptorBoard.kicad_pcb, CaptorBoard.sch]
2015-04-26 Error of ref
    [CaptorBoard.sch]
2015-04-26 New bom
    [CaptorBoard.xlsx]
2015-05-04 Change led package to 3mm
    [CaptorBoard.kicad_pcb, CaptorBoard.sch, CaptorBoard.xlsx]
2015-05-04 Change RH/temp sensor to STH21
    [CaptorBoard.kicad_pcb, CaptorBoard.sch, CaptorBoard.xlsx]
2015-05-04 Change Button ref
    [CaptorBoard.kicad_pcb, CaptorBoard.sch, CaptorBoard.xlsx]
2017-12-18 last version
    [CaptorBoard.xlsx]
2018-07-26 finally use WeMos Mini
    [CaptorBoard-2018-04-15-11-25-39.sch, CaptorBoard.csv, CaptorBoard.kicad_pcb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]
2020-06-21 Board final
    [CaptorBoard-B_Cu.gbl, CaptorBoard-B_Mask.gbs, CaptorBoard-B_SilkS.gbo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]
2020-11-19 new kicad version
    [CaptorBoard.kicad_pcb, CaptorBoard.kicad_sch]
2020-11-19 production files
    [CaptorBoard-B_Cu.gbl, CaptorBoard-B_Mask.gbs, CaptorBoard-B_SilkS.gbo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]
2020-12-10 add pull up for booting conditions
    [CaptorBoard.kicad_pcb, CaptorBoard.kicad_sch]
2021-04-21 with new kicad version
    [CaptorBoard.kicad_pcb, CaptorBoard.kicad_sch]
2021-12-02 new kicad
    [CaptorBoard.kicad_pcb, CaptorBoard.kicad_sch]
2022-11-18 Add new 3D
    [IRM-05-5.stp, Relay_SPDT_Omron-G5LE-1.step]
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2022-11-18 Remove wemos D1 for ESP32-WROOM-32
    [CaptorBoard.kicad_sch]
2022-11-18 New routing
    [CaptorBoard.kicad_pcb]
2022-11-21 move sector track for more isolating
    [CaptorBoard.kicad_pcb]
2022-11-21 Change routing and add logo
    [CaptorBoard.kicad_pcb]
2022-11-25 update ref
    [CaptorBoard.csv, CaptorBoard.kicad_pcb, CaptorBoard.kicad_sch]
2022-11-28 add serigraphie
    [CaptorBoard.kicad_pcb]
2022-11-28 remove bad net
    [CaptorBoard.kicad_sch]
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2022-12-01 update bon and cost
    [CaptorBoard.xlsx]
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2022-12-08 Add open source hardware logo
    [CaptorBoard.kicad_pcb, CaptorBoard.kicad_sch]
2022-12-23 use only step file for 3D render
    [CaptorBoard.kicad_pcb]
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2023-01-20 Change relait and LED schematic
    [CaptorBoard.kicad_pcb, CaptorBoard.kicad_sch]
2023-01-20 new production files export
    [CaptorBoard-B_Cu.gbl, CaptorBoard-B_Mask.gbs, CaptorBoard-B_Silkscreen.gbo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]
2023-01-26 Add top and bottom track for relais output
    [CaptorBoard.kicad_pcb]
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2023-04-02 Add new component into lib
    [PSK-5D-5.stp]
2023-04-02 Change AC/DC converter for one smaller and chiper
    [CaptorBoard.kicad_sch]
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2023-04-13 Add split for isolation on relais contact side
    [CaptorBoard.kicad_pcb]
2023-05-01 Change somme manufacturer referance
    [CaptorBoard.csv, CaptorBoard.kicad_sch, CaptorBoard.xlsx]
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2023-05-01 change power label name because their are not the same
    [CaptorBoard.kicad_sch]
2023-05-01 update manufacturer reference into pcb
    [CaptorBoard.kicad_pcb]
2023-06-07 Add two more anlog input and protect it
    [CaptorBoard.kicad_sch]
2023-06-07 route the new analog input and protections
    [CaptorBoard.kicad_pcb]
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2023-06-22 Change connecteur and pin for a better routing
    [CaptorBoard.kicad_sch]
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2023-06-28 add CEM protection, and change reférance for Digikey distributor
    [CaptorBoard-B_Cu.gbl, CaptorBoard-B_Mask.gbs, CaptorBoard-B_Silkscreen.gbo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]
2023-07-10 change a bad foot print for fuse
    [3403.0176.24.stp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]
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2023-08-26 Change ANA0 ESP32 input the ADC2 is not use-able if the WIFI is active
    [CaptorBoard.kicad_sch]
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2024-05-08 Migrate to Kicad 8.0
    [Back.FCStd, CaptorBoard.kicad_pcb, CaptorBoard.kicad_sch]
